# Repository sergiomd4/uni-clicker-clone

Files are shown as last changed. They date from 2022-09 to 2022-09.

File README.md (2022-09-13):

UNI Clicker Clone
========================================

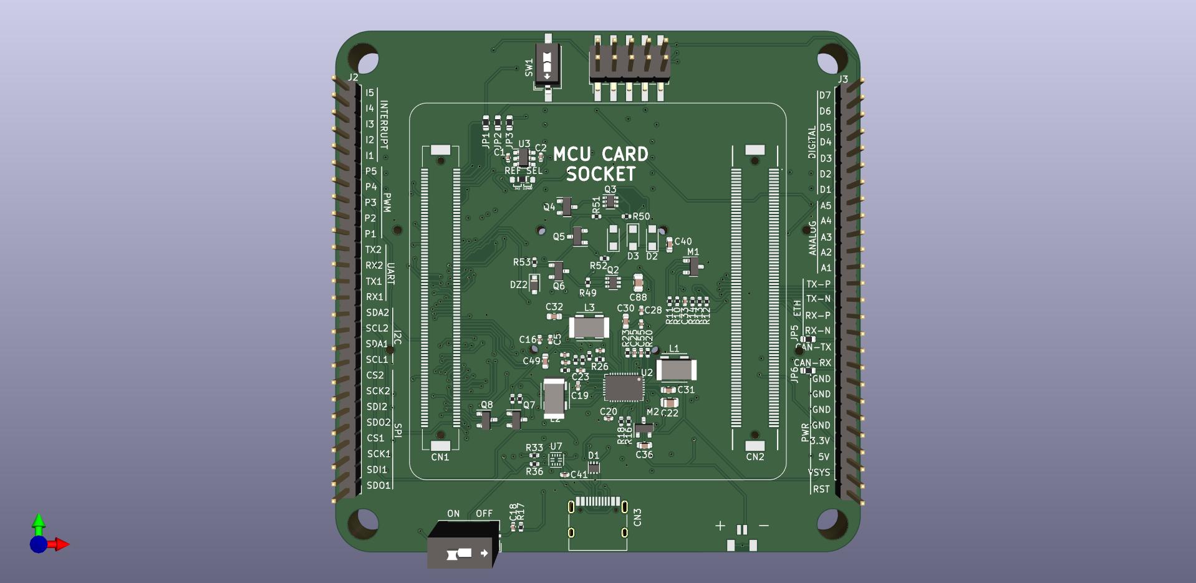
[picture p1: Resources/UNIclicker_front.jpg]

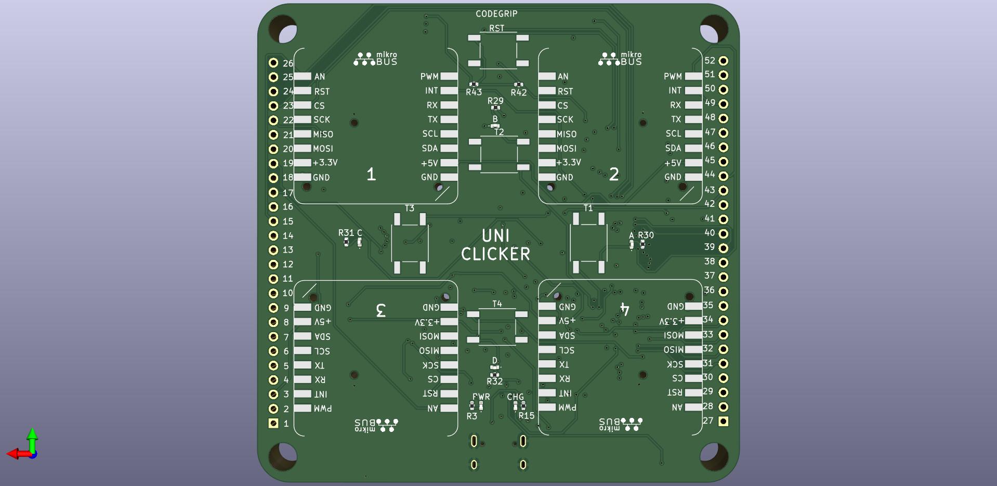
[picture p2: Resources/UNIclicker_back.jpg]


UNI Clicker is a compact development board designed as a complete solution. It contains a MCU Card socket, four mikroBUS sockets for Click boards connectivity and power management. 

Its core is a MCU Card socket that allows UNI Clicker to use different microcontrollers mounted on a standardized MCU Card. The MCU Card can be connected to the UNI Clicker by two 168-pin mezzanine connectors, one male and one female. This MCU Card supports architectures such as ARM, PIC32, dsPIC, PIC, AVR, Microchip, ST, NXP, TI and more.

UNI Clicker can be powered on by a small switch at the edge of the board. Therefore, the PSU (Power Supply Unit) module will be enabled and the power will be distributed. The PWR LED indicates that the board is ON.

Repository Contents
-------------------

* **/Production** - Gerber files, drill files, BOM, CPL file
* **/Hardware** - KiCad PCB files, footprints library
* **/Documents** - Schematics pdf

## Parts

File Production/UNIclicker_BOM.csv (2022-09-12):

Source: | C:\Users\Sergio\Documents\EOS\UNIclicker\UNIclicker\UNIclicker.kicad_sch
Date: | 29/08/2022 18:50:23
Tool: | Eeschema (6.0.7)
Generator: | C:\Program Files\KiCad\6.0\bin\scripting\plugins/bom_csv_grouped_by_value.py
Component Count: | 101
Individual Components:
Item | Qty | Reference(s) | Value | LibPart | Footprint | Datasheet | LCSC Part Number
 |  | C1 | 1u | Device:C | Capacitor_SMD:C_0402_1005Metric | ~ | C14445
 |  | C2 | 100n | Device:C | Capacitor_SMD:C_0402_1005Metric | ~ | C60474
 |  | C5 | 1u | Device:C | Capacitor_SMD:C_0402_1005Metric | ~ | C14445
 |  | C16 | 10000p | Device:C | Capacitor_SMD:C_0402_1005Metric | ~ | C60133
 |  | C18 | 0.1u | Device:C | Capacitor_SMD:C_0402_1005Metric | ~ | C1525
 |  | C19 | 2.2u | Device:C | Capacitor_SMD:C_0402_1005Metric | ~ | C107369
 |  | C20 | 2.2u | Device:C | Capacitor_SMD:C_0402_1005Metric | ~ | C107369
 |  | C21 | 33p | Device:C | Capacitor_SMD:C_0402_1005Metric | ~ | C1562
 |  | C22 | 47u | Device:C | Capacitor_SMD:C_0805_2012Metric | ~ | C16780
 |  | C23 | 10p | Device:C | Capacitor_SMD:C_0402_1005Metric | ~ | C696913
 |  | C24 | 300p | Device:C | Capacitor_SMD:C_0402_1005Metric | ~ | C1534
 |  | C25 | 0.1u | Device:C | Capacitor_SMD:C_0402_1005Metric | ~ | C1525
 |  | C27 | 1u | Device:C | Capacitor_SMD:C_0402_1005Metric | ~ | C14445
 |  | C28 | 10000p | Device:C | Capacitor_SMD:C_0402_1005Metric | ~ | C60133
 |  | C29 | 10p | Device:C | Capacitor_SMD:C_0402_1005Metric | ~ | C696913
 |  | C30 | 22u | Device:C | Capacitor_SMD:C_0603_1608Metric | ~ | C59461
 |  | C31 | 22u | Device:C | Capacitor_SMD:C_0603_1608Metric | ~ | C59461
 |  | C32 | 10u | Device:C | Capacitor_SMD:C_0603_1608Metric | ~ | C19702
 |  | C33 | 0.1u | Device:C | Capacitor_SMD:C_0402_1005Metric | ~ | C1525
 |  | C36 | 10u | Device:C | Capacitor_SMD:C_0603_1608Metric | ~ | C19702
 |  | C40 | 10u | Device:C | Capacitor_SMD:C_0603_1608Metric | ~ | C19702
 |  | C41 | 100n | Device:C | Capacitor_SMD:C_0402_1005Metric | ~ | C60474
 |  | C49 | 22u | Device:C | Capacitor_SMD:C_0603_1608Metric | ~ | C59461
 |  | C55 | 1u | Device:C | Capacitor_SMD:C_0402_1005Metric | ~ | C14445
 |  | C88 | 47u | Device:C | Capacitor_SMD:C_0805_2012Metric | ~ | C16780
 |  | CN1 | FX10A-168P-SV(71) | UNIclicker:MCU_CARD_SOCKET | EOS:FX10A-168P-SV(71) |  | C598050
 |  | CN2 | FX10A-168S-SV | UNIclicker:MCU_CARD_SOCKET | EOS:FX10A-168S-SV |  | C598051
 |  | CN3 | USB_C_Receptacle_USB2.0 | Connector:USB_C_Receptacle_USB2.0 | Connector_USB:USB_C_Receptacle_HRO_TYPE-C-31-M-12 | https://www.usb.org/sites/default/files/documents/usb_type-c.zip | C709357
 |  | D1 | USBLC6-2P6 | UNIclicker:USBLC6-2P6 | EOS:USBLC6-2P6 |  | C2827693
 |  | D2 | PMEG3010ER | Diode:PMEG3010ER | Diode_SMD:Nexperia_CFP3_SOD-123W | https://assets.nexperia.com/documents/data-sheet/PMEG3010ER.pdf | C456106
 |  | D3 | PMEG3010ER | Diode:PMEG3010ER | Diode_SMD:Nexperia_CFP3_SOD-123W | https://assets.nexperia.com/documents/data-sheet/PMEG3010ER.pdf | C456106
 |  | D4 | PMEG3010ER | Diode:PMEG3010ER | Diode_SMD:Nexperia_CFP3_SOD-123W | https://assets.nexperia.com/documents/data-sheet/PMEG3010ER.pdf | C456106
 |  | DZ2 | MM3Z3V3B | Device:D_Zener | EOS:MM3Z3V3B | ~ | C556407
 |  | J1 | DS1069-11 | UNIclicker:DS1069-11 | EOS:DS1069-11 |  | C160388
 |  | J10 | HM2X5 | Connector_Generic:Conn_02x05_Odd_Even | EOS:J10 | ~ | C124391
 |  | JP1 | 0.0 | Device:R | Resistor_SMD:R_0603_1608Metric | ~ | C122704
 |  | JP2 | 0.0 | Device:R | Resistor_SMD:R_0603_1608Metric | ~ | C122704
 |  | JP3 | 0.0 | Device:R | Resistor_SMD:R_0603_1608Metric | ~ | C122704
 |  | JP4 | REF SEL | Connector:Conn_01x03_Female | EOS:JP4 | ~ | C122704
 |  | JP5 | 0.0 | Device:R | Resistor_SMD:R_0603_1608Metric | ~ | C122704
 |  | JP6 | 0.0 | Device:R | Resistor_SMD:R_0603_1608Metric | ~ | C122704
 |  | L1 | 3.3u | Device:L | EOS:L1 | ~ | C15269
 |  | L2 | 2.2u | Device:L | EOS:L1 | ~ | C38117
 |  | L3 | 2.2u | Device:L | EOS:L1 | ~ | C38117
 |  | LED1 | CHG | Device:LED | LED_SMD:LED_0402_1005Metric | ~ | C965790
 |  | LED2 | PWR | Device:LED | LED_SMD:LED_0402_1005Metric | ~ | C434446
 |  | LED3 | A | Device:LED | LED_SMD:LED_0402_1005Metric | ~ | C965790
 |  | LED4 | B | Device:LED | LED_SMD:LED_0402_1005Metric | ~ | C965790
 |  | LED5 | C | Device:LED | LED_SMD:LED_0402_1005Metric | ~ | C965790
 |  | LED6 | D | Device:LED | LED_SMD:LED_0402_1005Metric | ~ | C965790
 |  | M1 | DMP2305U-7 | Transistor_FET:2N7002 | Package_TO_SOT_SMD:SOT-23 | https://www.onsemi.com/pub/Collateral/NDS7002A-D.PDF | C85097
 |  | M2 | DMP2305U-7 | Transistor_FET:2N7002 | Package_TO_SOT_SMD:SOT-23 | https://www.onsemi.com/pub/Collateral/NDS7002A-D.PDF | C85097
 |  | Q2 | DMP1046UFDB-7 | Transistor_FET:BSD235C | Package_TO_SOT_SMD:SOT-363_SC-70-6 | https://www.infineon.com/dgdl/Infineon-BSD235C-DS-v02_04-EN.pdf?fileId=db3a30433580b371013585a2d0d53326 | C131781
 |  | Q3 | DMP1046UFDB-7 | Transistor_FET:BSD235C | Package_TO_SOT_SMD:SOT-363_SC-70-6 | https://www.infineon.com/dgdl/Infineon-BSD235C-DS-v02_04-EN.pdf?fileId=db3a30433580b371013585a2d0d53326 | C131781
 |  | Q4 | BSS138 | Transistor_FET:BSS138 | Package_TO_SOT_SMD:SOT-23 | https://www.onsemi.com/pub/Collateral/BSS138-D.PDF | C112239
 |  | Q5 | BSS138 | Transistor_FET:BSS138 | Package_TO_SOT_SMD:SOT-23 | https://www.onsemi.com/pub/Collateral/BSS138-D.PDF | C112239
 |  | Q6 | BSS138 | Transistor_FET:BSS138 | Package_TO_SOT_SMD:SOT-23 | https://www.onsemi.com/pub/Collateral/BSS138-D.PDF | C112239
 |  | Q7 | DMG3420U-7 | Transistor_FET:2N7002 | Package_TO_SOT_SMD:SOT-23 | https://www.onsemi.com/pub/Collateral/NDS7002A-D.PDF | C154722
 |  | Q8 | DMG3420U-7 | Transistor_FET:2N7002 | Package_TO_SOT_SMD:SOT-23 | https://www.onsemi.com/pub/Collateral/NDS7002A-D.PDF | C154722
 |  | R3 | 470 | Device:R | Resistor_SMD:R_0402_1005Metric | ~ | C25117
 |  | R10 | 1M | Device:R | Resistor_SMD:R_0402_1005Metric | ~ | C93949
 |  | R11 | 1k | Device:R | Resistor_SMD:R_0402_1005Metric | ~ | C226166
 |  | R12 | 100k | Device:R | Resistor_SMD:R_0402_1005Metric | ~ | C25741
 |  | R13 | 100k | Device:R | Resistor_SMD:R_0402_1005Metric | ~ | C25741
 |  | R14 | 100k | Device:R | Resistor_SMD:R_0402_1005Metric | ~ | C25741
 |  | R15 | 2.2k | Device:R | Resistor_SMD:R_0402_1005Metric | ~ | C25879
 |  | R16 | 10k | Device:R | Resistor_SMD:R_0402_1005Metric | ~ | C140214
 |  | R17 | 1k | Device:R | Resistor_SMD:R_0402_1005Metric | ~ | C226166
 |  | R18 | 3.3k | Device:R | Resistor_SMD:R_0402_1005Metric | ~ | C25890
 |  | R19 | 324k | Device:R | Resistor_SMD:R_0402_1005Metric | ~ | C113480
 |  | R20 | 10k | Device:R | Resistor_SMD:R_0402_1005Metric | ~ | C140214
 |  | R21 | 15k | Device:R | Resistor_SMD:R_0402_1005Metric | ~ | C25756
 |  | R22 | 105k | Device:R | Resistor_SMD:R_0402_1005Metric | ~ | C25742
 |  | R23 | 1.69k | Device:R | Resistor_SMD:R_0402_1005Metric | ~ | C25870
 |  | R26 | 88.7k | Device:R | Resistor_SMD:R_0402_1005Metric | ~ | C25922
 |  | R27 | 16.9k | Device:R | Resistor_SMD:R_0402_1005Metric | ~ | C25858
 |  | R29 | 1k | Device:R | Resistor_SMD:R_0402_1005Metric | ~ | C226166
 |  | R30 | 1k | Device:R | Resistor_SMD:R_0402_1005Metric | ~ | C226166
 |  | R31 | 1k | Device:R | Resistor_SMD:R_0402_1005Metric | ~ | C226166
 |  | R32 | 1k | Device:R | Resistor_SMD:R_0402_1005Metric | ~ | C226166
 |  | R33 | 1k | Device:R | Resistor_SMD:R_0402_1005Metric | ~ | C226166
 |  | R36 | 4.7k | Device:R | Resistor_SMD:R_0402_1005Metric | ~ | C304616
 |  | R40 | 10k | Device:R | Resistor_SMD:R_0402_1005Metric | ~ | C140214
 |  | R41 | 100k | Device:R | Resistor_SMD:R_0402_1005Metric | ~ | C25741
 |  | R42 | 10k | Device:R | Resistor_SMD:R_0402_1005Metric | ~ | C140214
 |  | R43 | 330 | Device:R | Resistor_SMD:R_0402_1005Metric | ~ | C12246
 |  | R49 | 10k | Device:R | Resistor_SMD:R_0402_1005Metric | ~ | C140214
 |  | R50 | 47k | Device:R | Resistor_SMD:R_0402_1005Metric | ~ | C25563
 |  | R51 | 10k | Device:R | Resistor_SMD:R_0402_1005Metric | ~ | C140214
 |  | R52 | 5.1k | Device:R | Resistor_SMD:R_0402_1005Metric | ~ | C25905
 |  | R53 | 12.1k | Device:R | Resistor_SMD:R_0402_1005Metric | ~ | C25852
 |  | SW1 | CHS-01TB | Switch:SW_DIP_x01 | EOS:CHS-01TB | ~ | C54948
 |  | SW2 | JS202011JCQN | UNIclicker:JS202011JCQN | EOS:JS202011JCQN |  | C221665
 |  | T1 | SW_Push_Dual | Switch:SW_Push_Dual | EOS:PUSH_BUTTON | ~ | C127509
 |  | T2 | SW_Push_Dual | Switch:SW_Push_Dual | EOS:PUSH_BUTTON | ~ | C127509
 |  | T3 | SW_Push_Dual | Switch:SW_Push_Dual | EOS:PUSH_BUTTON | ~ | C127509
 |  | T4 | SW_Push_Dual | Switch:SW_Push_Dual | EOS:PUSH_BUTTON | ~ | C127509
 |  | T5 | SW_Push_Dual | Switch:SW_Push_Dual | EOS:PUSH_BUTTON | ~ | C127509
 |  | U2 | LTC3586EUFE | UNIclicker:LTC3586EUFE | Package_DFN_QFN:QFN-38-1EP_4x6mm_P0.4mm_EP2.65x4.65mm |  | C685109
 |  | U3 | MCP1501T-20E/RW | UNIclicker:MCP1501T-20E{slash}RW | Package_TO_SOT_SMD:SOT-23-6 |  | C98139
 |  | U7 | PTN5150AHXMP | UNIclicker:PTN5150AHXMP | EOS:PTN5150AHXMP |  | C2651889

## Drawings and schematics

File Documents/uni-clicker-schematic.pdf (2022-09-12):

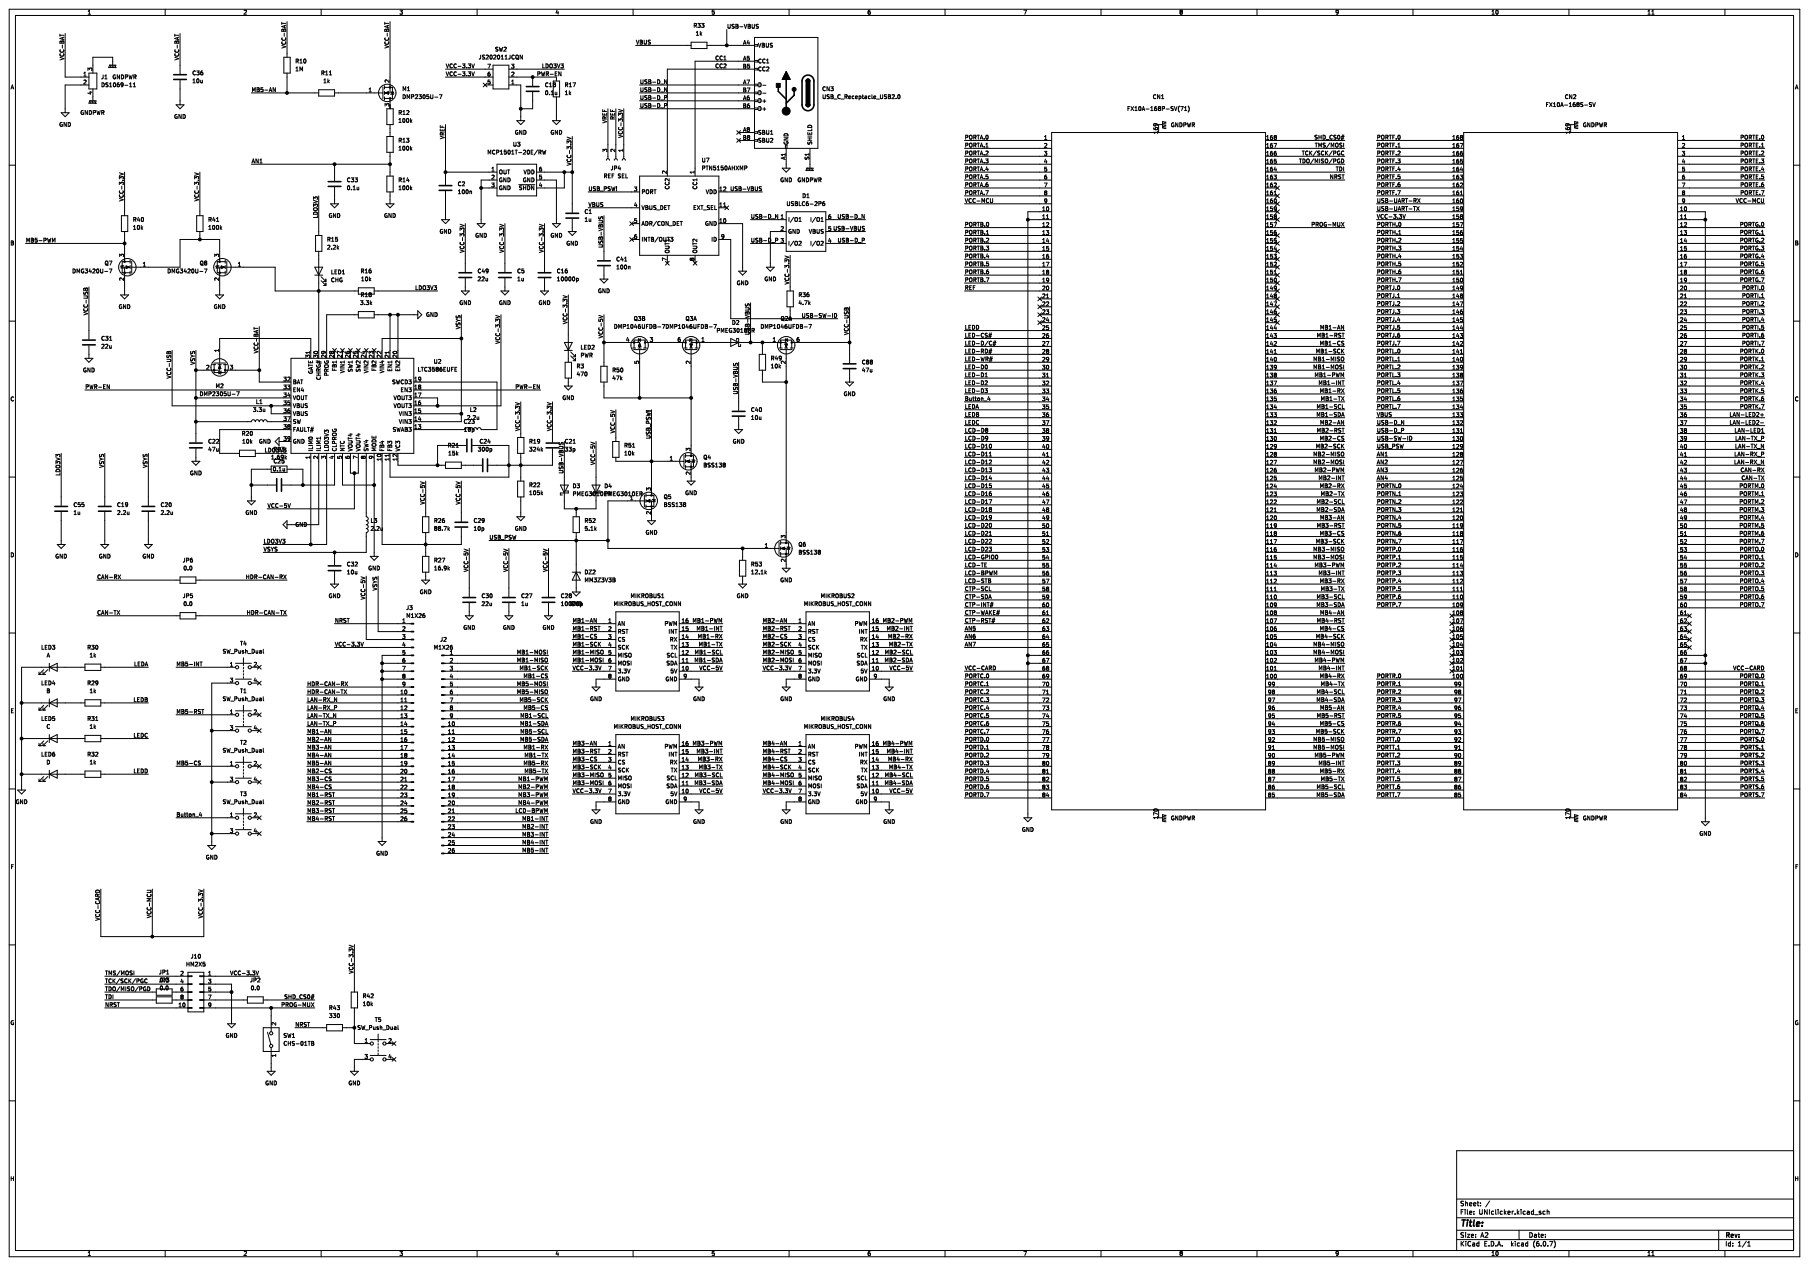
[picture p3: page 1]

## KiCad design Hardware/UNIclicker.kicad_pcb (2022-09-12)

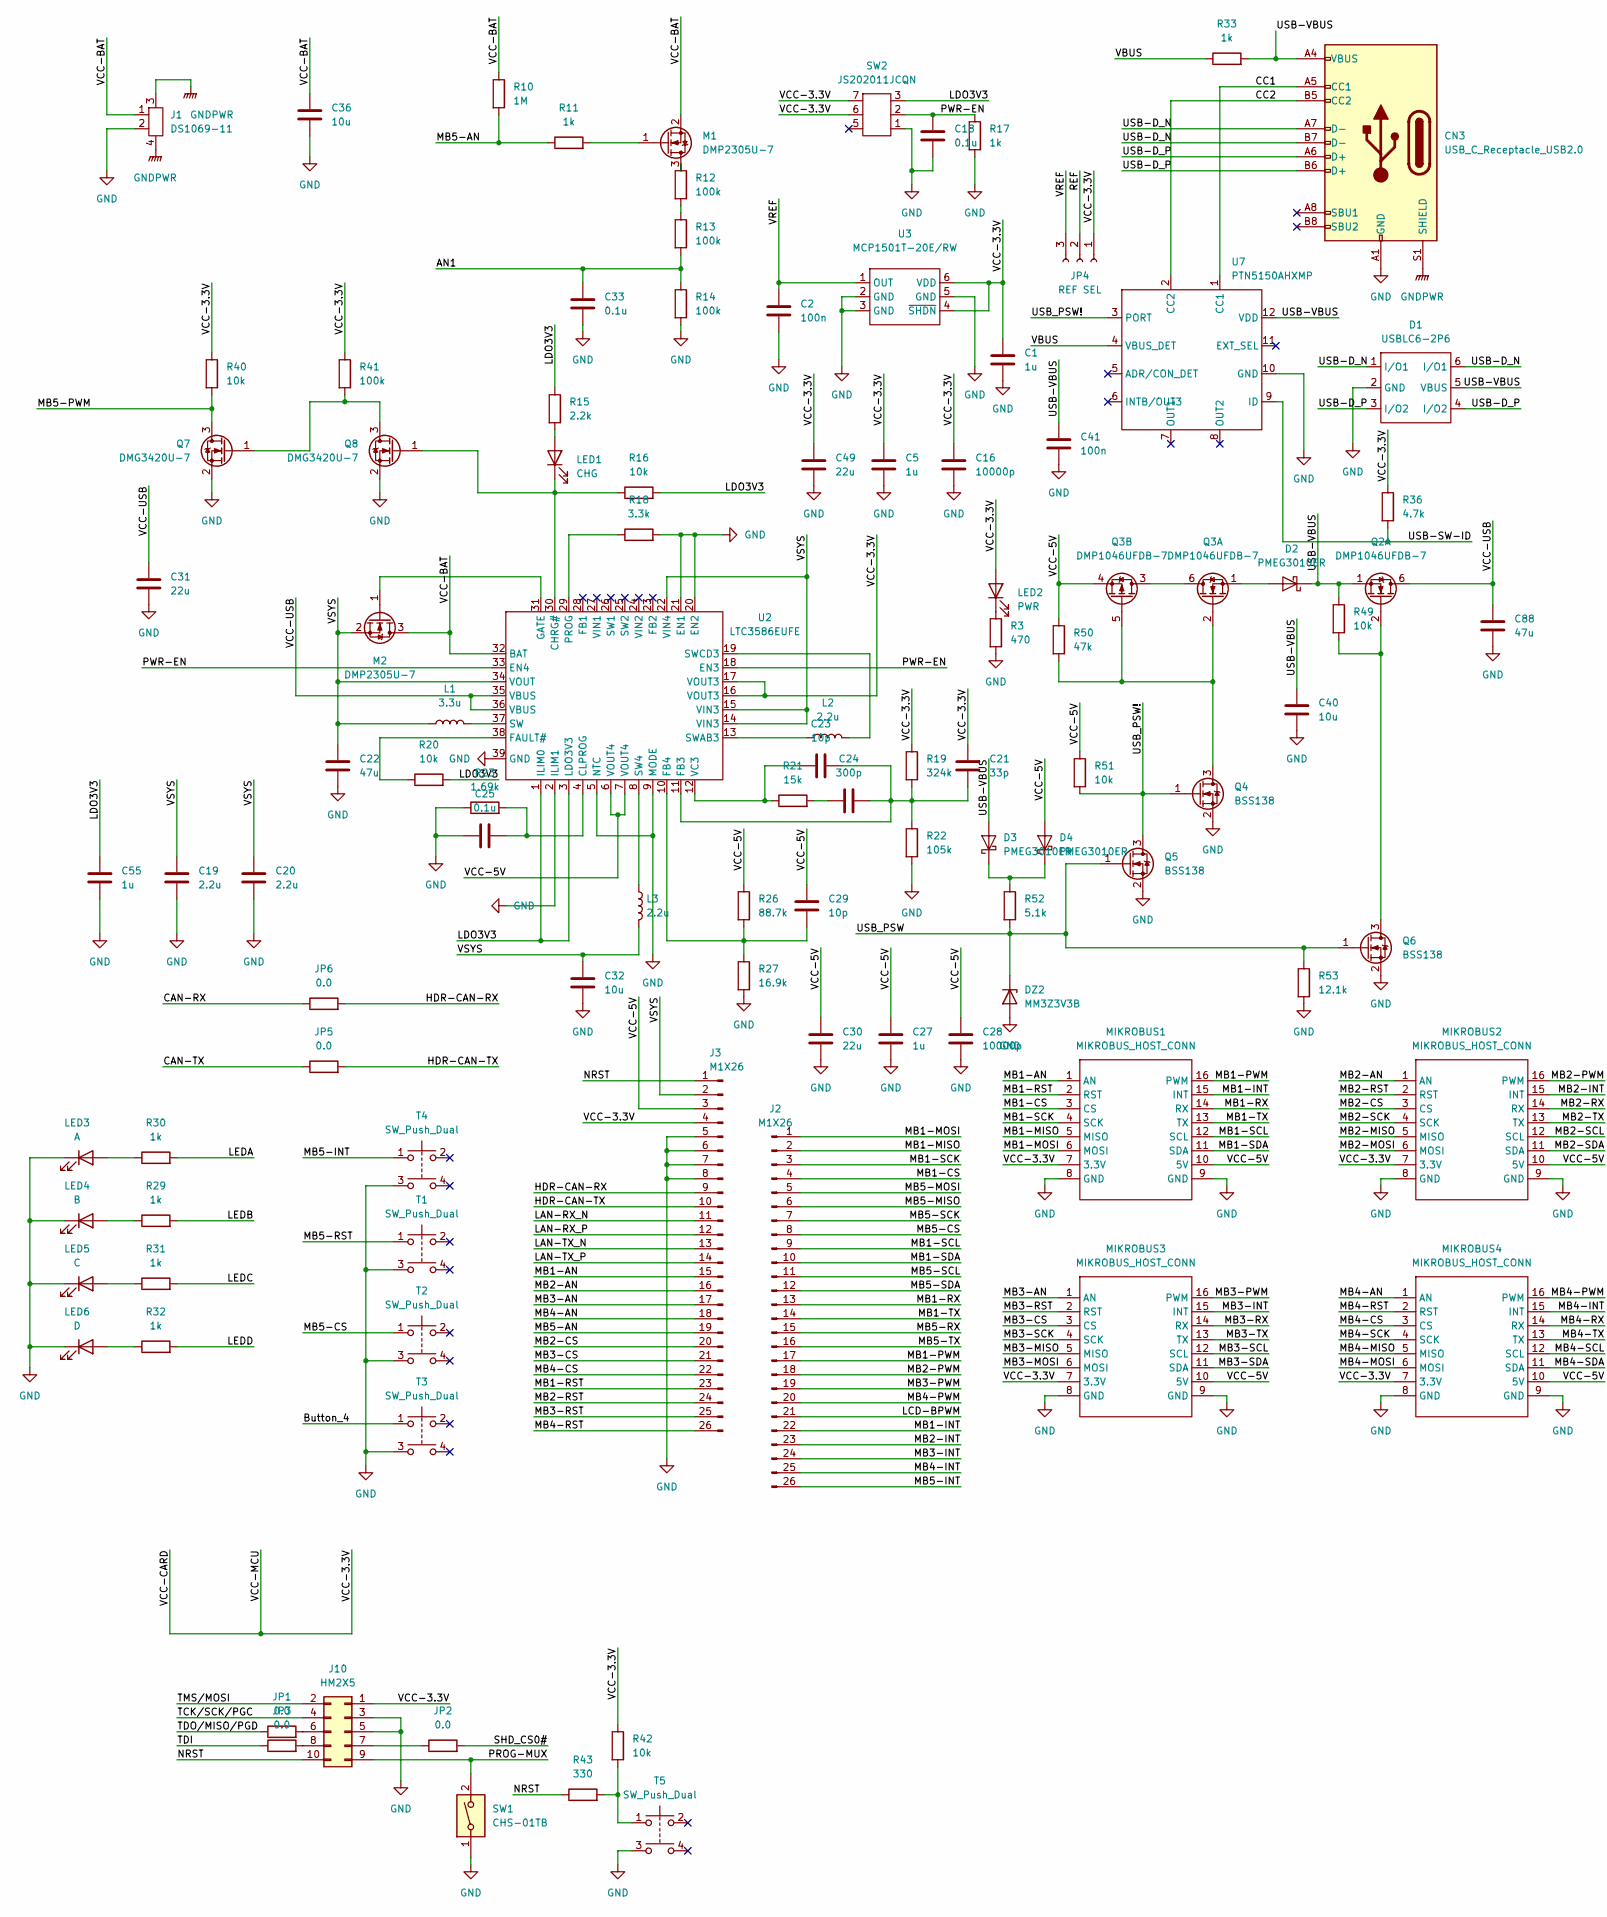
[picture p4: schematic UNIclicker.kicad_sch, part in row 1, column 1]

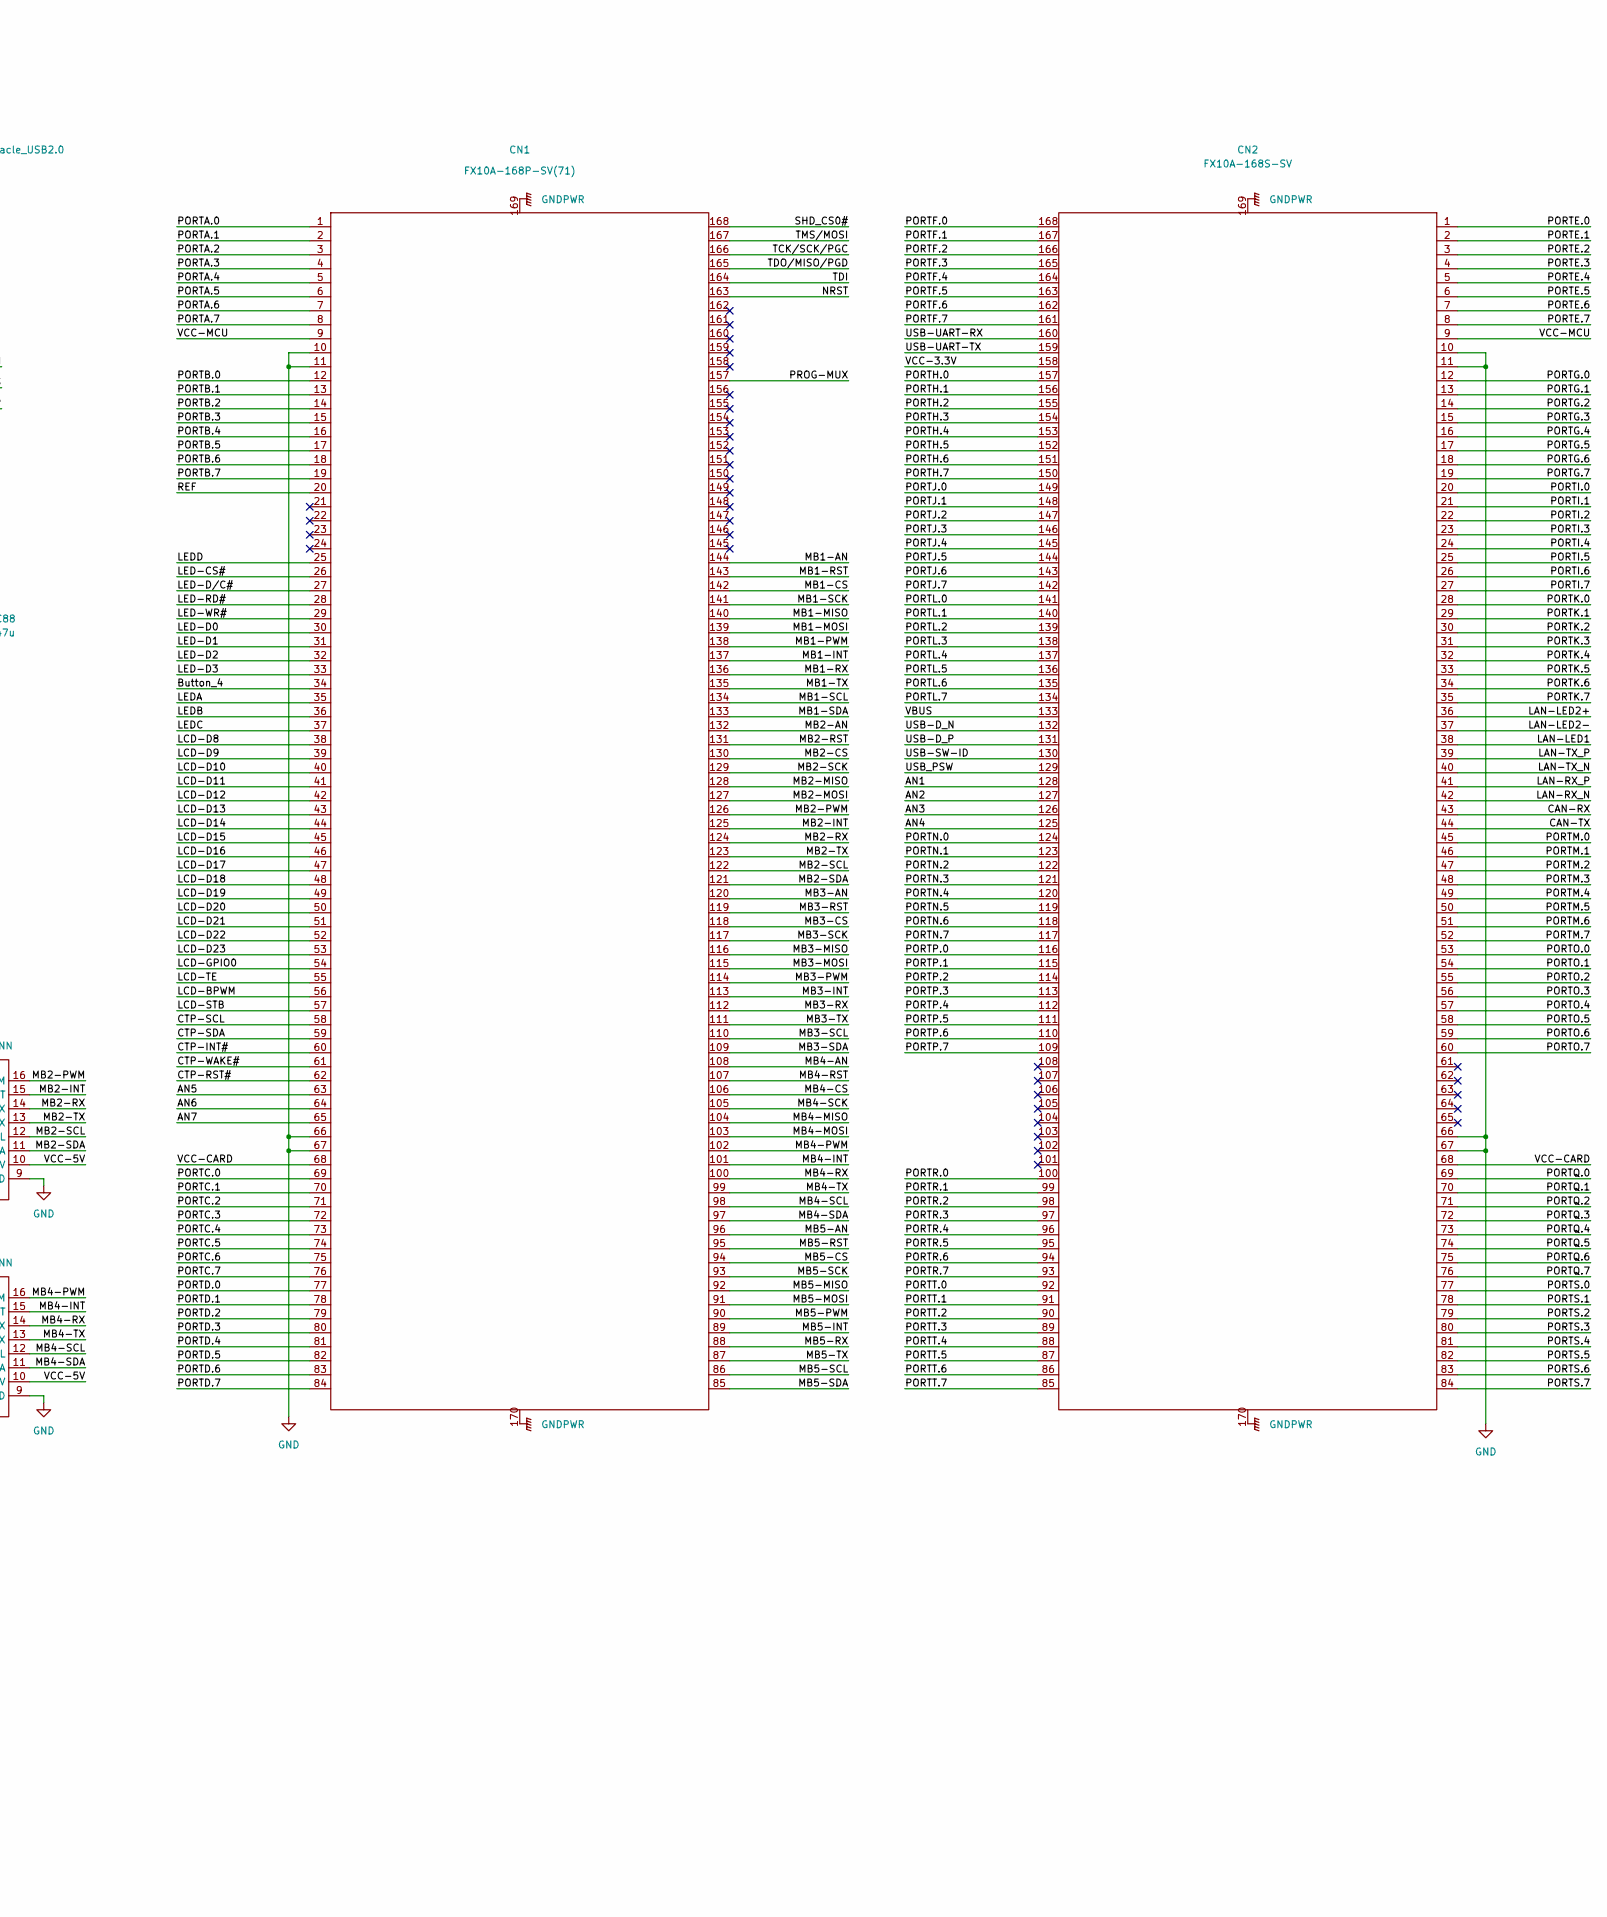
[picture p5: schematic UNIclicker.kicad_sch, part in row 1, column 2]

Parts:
C1, C5, C27, C55: 1u; C_0402_1005Metric; LCSC Part Number C14445
C2, C41: 100n; C_0402_1005Metric; LCSC Part Number C60474
C16, C28: 10000p; C_0402_1005Metric; LCSC Part Number C60133
C18, C25, C33: 0.1u; C_0402_1005Metric; LCSC Part Number C1525
C19, C20: 2.2u; C_0402_1005Metric; LCSC Part Number C107369
C21: 33p; C_0402_1005Metric; LCSC Part Number C1562
C22, C88: 47u; C_0805_2012Metric; LCSC Part Number C16780
C23, C29: 10p; C_0402_1005Metric; LCSC Part Number C696913
C24: 300p; C_0402_1005Metric; LCSC Part Number C1534
C30, C31, C49: 22u; C_0603_1608Metric; LCSC Part Number C59461
C32, C36, C40: 10u; C_0603_1608Metric; LCSC Part Number C19702
CN1: FX10A-168P-SV(71); LCSC Part Number C598050
CN2: FX10A-168S-SV; LCSC Part Number C598051
CN3: USB_C_Receptacle_USB2.0; USB_C_Receptacle_HRO_TYPE-C-31-M-12; LCSC Part Number C709357
D1: USBLC6-2P6; LCSC Part Number C2827693
D2, D3, D4: PMEG3010ER; Nexperia_CFP3_SOD-123W; LCSC Part Number C456106
DZ2: MM3Z3V3B; LCSC Part Number C556407
J1: DS1069-11; LCSC Part Number C160388
J2, J3: M1X26; PinHeader_1x26_P2.54mm_Vertical
J10: HM2X5; J10; LCSC Part Number C124391
JP1, JP2, JP3, JP5, JP6: 0.0; R_0603_1608Metric; LCSC Part Number C122704
JP4: REF SEL; JP4; LCSC Part Number C122704
L1: 3.3u; L1; LCSC Part Number C15269
L2, L3: 2.2u; L1; LCSC Part Number C38117
LED1: CHG; LED_0402_1005Metric; LCSC Part Number C965790
LED2: PWR; LED_0402_1005Metric; LCSC Part Number C434446
LED3: A; LED_0402_1005Metric; LCSC Part Number C965790
LED4: B; LED_0402_1005Metric; LCSC Part Number C965790
LED5: C; LED_0402_1005Metric; LCSC Part Number C965790
LED6: D; LED_0402_1005Metric; LCSC Part Number C965790
M1, M2: DMP2305U-7; SOT-23; LCSC Part Number C85097
MIKROBUS1, MIKROBUS2, MIKROBUS3, MIKROBUS4: MIKROBUS_HOST_CONN; SOCKET MIKROBUS
Q2, Q3: DMP1046UFDB-7; SOT-363_SC-70-6; LCSC Part Number C131781
Q4, Q5, Q6: BSS138; SOT-23; LCSC Part Number C112239
Q7, Q8: DMG3420U-7; SOT-23; LCSC Part Number C154722
R3: 470; R_0402_1005Metric; LCSC Part Number C25117
R10: 1M; R_0402_1005Metric; LCSC Part Number C93949
R11, R17, R29, R30, R31, R32, R33: 1k; R_0402_1005Metric; LCSC Part Number C226166
R12, R13, R14, R41: 100k; R_0402_1005Metric; LCSC Part Number C25741
R15: 2.2k; R_0402_1005Metric; LCSC Part Number C25879
R16, R20, R40, R42, R49, R51: 10k; R_0402_1005Metric; LCSC Part Number C140214
R18: 3.3k; R_0402_1005Metric; LCSC Part Number C25890
R19: 324k; R_0402_1005Metric; LCSC Part Number C113480
R21: 15k; R_0402_1005Metric; LCSC Part Number C25756
R22: 105k; R_0402_1005Metric; LCSC Part Number C25742
R23: 1.69k; R_0402_1005Metric; LCSC Part Number C25870
R26: 88.7k; R_0402_1005Metric; LCSC Part Number C25922
R27: 16.9k; R_0402_1005Metric; LCSC Part Number C25858
R36: 4.7k; R_0402_1005Metric; LCSC Part Number C304616
R43: 330; R_0402_1005Metric; LCSC Part Number C12246
R50: 47k; R_0402_1005Metric; LCSC Part Number C25563
R52: 5.1k; R_0402_1005Metric; LCSC Part Number C25905
R53: 12.1k; R_0402_1005Metric; LCSC Part Number C25852
SW1: CHS-01TB; LCSC Part Number C54948
SW2: JS202011JCQN; LCSC Part Number C221665
T1, T2, T3, T4, T5: SW_Push_Dual; PUSH_BUTTON; LCSC Part Number C127509
U2: LTC3586EUFE; QFN-38-1EP_4x6mm_P0.4mm_EP2.65x4.65mm
U3: MCP1501T-20E/RW; SOT-23-6
U7: PTN5150AHXMP

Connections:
/AN1: C33.1, CN2.128, R13.2, R14.1
/AN2: CN2.127
/AN3: CN2.126
/AN4: CN2.125
/AN5: CN1.63
/AN6: CN1.64
/AN7: CN1.65
/Button_4: CN1.34, T3.1
/CAN-RX: CN2.43, JP6.1
/CAN-TX: CN2.44, JP5.1
/CC1: CN3.A5 (CC1), U7.1 (CC1)
/CC2: CN3.B5 (CC2), U7.2 (CC2)
/CTP-INT#: CN1.60
/CTP-RST#: CN1.62
/CTP-SCL: CN1.58
/CTP-SDA: CN1.59
/CTP-WAKE#: CN1.61
/HDR-CAN-RX: J3.9, JP6.2
/HDR-CAN-TX: J3.10, JP5.2
/LAN-LED1: CN2.38
/LAN-LED2+: CN2.36
/LAN-LED2-: CN2.37
/LAN-RX_N: CN2.42, J3.11
/LAN-RX_P: CN2.41, J3.12
/LAN-TX_N: CN2.40, J3.13
/LAN-TX_P: CN2.39, J3.14
/LCD-BPWM: CN1.56, J2.21
/LCD-D8: CN1.38
/LCD-D9: CN1.39
/LCD-D10: CN1.40
/LCD-D11: CN1.41
/LCD-D12: CN1.42
/LCD-D13: CN1.43
/LCD-D14: CN1.44
/LCD-D15: CN1.45
/LCD-D16: CN1.46
/LCD-D17: CN1.47
/LCD-D18: CN1.48
/LCD-D19: CN1.49
/LCD-D20: CN1.50
/LCD-D21: CN1.51
/LCD-D22: CN1.52
/LCD-D23: CN1.53
/LCD-GPIO0: CN1.54
/LCD-STB: CN1.57
/LCD-TE: CN1.55
/LDO3V3: C55.1, R15.1, R16.2, R20.2, SW2.3, U2.1 (ILIM0), U2.3 (LDO3V3)
/LED-CS#: CN1.26
/LED-D0: CN1.30
/LED-D1: CN1.31
/LED-D2: CN1.32
/LED-D3: CN1.33
/LED-D/C#: CN1.27
/LED-RD#: CN1.28
/LED-WR#: CN1.29
/LEDA: CN1.35, R30.2
/LEDB: CN1.36, R29.2
/LEDC: CN1.37, R31.2
/LEDD: CN1.25, R32.2
/MB1-AN: CN1.144, J3.15, MIKROBUS1.1 (AN)
/MB1-CS: CN1.142, J2.4, MIKROBUS1.3 (CS)
/MB1-INT: CN1.137, J2.22, MIKROBUS1.15 (INT)
/MB1-MISO: CN1.140, J2.2, MIKROBUS1.5 (MISO)
/MB1-MOSI: CN1.139, J2.1, MIKROBUS1.6 (MOSI)
/MB1-PWM: CN1.138, J2.17, MIKROBUS1.16 (PWM)
/MB1-RST: CN1.143, J3.23, MIKROBUS1.2 (RST)
/MB1-RX: CN1.136, J2.13, MIKROBUS1.14 (RX)
/MB1-SCK: CN1.141, J2.3, MIKROBUS1.4 (SCK)
/MB1-SCL: CN1.134, J2.9, MIKROBUS1.12 (SCL)
/MB1-SDA: CN1.133, J2.10, MIKROBUS1.11 (SDA)
/MB1-TX: CN1.135, J2.14, MIKROBUS1.13 (TX)
/MB2-AN: CN1.132, J3.16, MIKROBUS2.1 (AN)
/MB2-CS: CN1.130, J3.20, MIKROBUS2.3 (CS)
/MB2-INT: CN1.125, J2.23, MIKROBUS2.15 (INT)
/MB2-MISO: CN1.128, MIKROBUS2.5 (MISO)
/MB2-MOSI: CN1.127, MIKROBUS2.6 (MOSI)
/MB2-PWM: CN1.126, J2.18, MIKROBUS2.16 (PWM)
/MB2-RST: CN1.131, J3.24, MIKROBUS2.2 (RST)
/MB2-RX: CN1.124, MIKROBUS2.14 (RX)
/MB2-SCK: CN1.129, MIKROBUS2.4 (SCK)
/MB2-SCL: CN1.122, MIKROBUS2.12 (SCL)
/MB2-SDA: CN1.121, MIKROBUS2.11 (SDA)
/MB2-TX: CN1.123, MIKROBUS2.13 (TX)
/MB3-AN: CN1.120, J3.17, MIKROBUS3.1 (AN)
/MB3-CS: CN1.118, J3.21, MIKROBUS3.3 (CS)
/MB3-INT: CN1.113, J2.24, MIKROBUS3.15 (INT)
/MB3-MISO: CN1.116, MIKROBUS3.5 (MISO)
/MB3-MOSI: CN1.115, MIKROBUS3.6 (MOSI)
/MB3-PWM: CN1.114, J2.19, MIKROBUS3.16 (PWM)
/MB3-RST: CN1.119, J3.25, MIKROBUS3.2 (RST)
/MB3-RX: CN1.112, MIKROBUS3.14 (RX)
/MB3-SCK: CN1.117, MIKROBUS3.4 (SCK)
/MB3-SCL: CN1.110, MIKROBUS3.12 (SCL)
/MB3-SDA: CN1.109, MIKROBUS3.11 (SDA)
/MB3-TX: CN1.111, MIKROBUS3.13 (TX)
/MB4-AN: CN1.108, J3.18, MIKROBUS4.1 (AN)
/MB4-CS: CN1.106, J3.22, MIKROBUS4.3 (CS)
/MB4-INT: CN1.101, J2.25, MIKROBUS4.15 (INT)
/MB4-MISO: CN1.104, MIKROBUS4.5 (MISO)
/MB4-MOSI: CN1.103, MIKROBUS4.6 (MOSI)
/MB4-PWM: CN1.102, J2.20, MIKROBUS4.16 (PWM)
/MB4-RST: CN1.107, J3.26, MIKROBUS4.2 (RST)
/MB4-RX: CN1.100, MIKROBUS4.14 (RX)
/MB4-SCK: CN1.105, MIKROBUS4.4 (SCK)
/MB4-SCL: CN1.98, MIKROBUS4.12 (SCL)
/MB4-SDA: CN1.97, MIKROBUS4.11 (SDA)
/MB4-TX: CN1.99, MIKROBUS4.13 (TX)
/MB5-AN: CN1.96, J3.19, R10.2, R11.1
/MB5-CS: CN1.94, J2.8, T2.1
/MB5-INT: CN1.89, J2.26, T4.1
/MB5-MISO: CN1.92, J2.6
/MB5-MOSI: CN1.91, J2.5
/MB5-PWM: CN1.90, Q7.3 (D), R40.2
/MB5-RST: CN1.95, T1.1
/MB5-RX: CN1.88, J2.15
/MB5-SCK: CN1.93, J2.7
/MB5-SCL: CN1.86, J2.11
/MB5-SDA: CN1.85, J2.12
/MB5-TX: CN1.87, J2.16
/NRST: CN1.163, J3.1, J10.10, R43.1
/PORTA.0: CN1.1
/PORTA.1: CN1.2
/PORTA.2: CN1.3
/PORTA.3: CN1.4
/PORTA.4: CN1.5
/PORTA.5: CN1.6
/PORTA.6: CN1.7
/PORTA.7: CN1.8
/PORTB.0: CN1.12
/PORTB.1: CN1.13
/PORTB.2: CN1.14
/PORTB.3: CN1.15
/PORTB.4: CN1.16
/PORTB.5: CN1.17
/PORTB.6: CN1.18
/PORTB.7: CN1.19
/PORTC.0: CN1.69
/PORTC.1: CN1.70
/PORTC.2: CN1.71
/PORTC.3: CN1.72
/PORTC.4: CN1.73
/PORTC.5: CN1.74
/PORTC.6: CN1.75
/PORTC.7: CN1.76
/PORTD.0: CN1.77
/PORTD.1: CN1.78
/PORTD.2: CN1.79
/PORTD.3: CN1.80
/PORTD.4: CN1.81
/PORTD.5: CN1.82
/PORTD.6: CN1.83
/PORTD.7: CN1.84
/PORTE.0: CN2.1
/PORTE.1: CN2.2
/PORTE.2: CN2.3
/PORTE.3: CN2.4
/PORTE.4: CN2.5
/PORTE.5: CN2.6
/PORTE.6: CN2.7
/PORTE.7: CN2.8
/PORTF.0: CN2.168
/PORTF.1: CN2.167
/PORTF.2: CN2.166
/PORTF.3: CN2.165
/PORTF.4: CN2.164
/PORTF.5: CN2.163
/PORTF.6: CN2.162
/PORTF.7: CN2.161
/PORTG.0: CN2.12
/PORTG.1: CN2.13
/PORTG.2: CN2.14
/PORTG.3: CN2.15
/PORTG.4: CN2.16
/PORTG.5: CN2.17
/PORTG.6: CN2.18
/PORTG.7: CN2.19
/PORTH.0: CN2.157
/PORTH.1: CN2.156
/PORTH.2: CN2.155
/PORTH.3: CN2.154
/PORTH.4: CN2.153
/PORTH.5: CN2.152
/PORTH.6: CN2.151
/PORTH.7: CN2.150
/PORTI.0: CN2.20
/PORTI.1: CN2.21
/PORTI.2: CN2.22
/PORTI.3: CN2.23
/PORTI.4: CN2.24
/PORTI.5: CN2.25
/PORTI.6: CN2.26
/PORTI.7: CN2.27
/PORTJ.0: CN2.149
/PORTJ.1: CN2.148
/PORTJ.2: CN2.147
/PORTJ.3: CN2.146
/PORTJ.4: CN2.145
/PORTJ.5: CN2.144
/PORTJ.6: CN2.143
/PORTJ.7: CN2.142
/PORTK.0: CN2.28
/PORTK.1: CN2.29
/PORTK.2: CN2.30
/PORTK.3: CN2.31
/PORTK.4: CN2.32
/PORTK.5: CN2.33
/PORTK.6: CN2.34
/PORTK.7: CN2.35
/PORTL.0: CN2.141
/PORTL.1: CN2.140
/PORTL.2: CN2.139
/PORTL.3: CN2.138
/PORTL.4: CN2.137
/PORTL.5: CN2.136
/PORTL.6: CN2.135
/PORTL.7: CN2.134
/PORTM.0: CN2.45
/PORTM.1: CN2.46
/PORTM.2: CN2.47
/PORTM.3: CN2.48
/PORTM.4: CN2.49
/PORTM.5: CN2.50
/PORTM.6: CN2.51
/PORTM.7: CN2.52
/PORTN.0: CN2.124
/PORTN.1: CN2.123
/PORTN.2: CN2.122
/PORTN.3: CN2.121
/PORTN.4: CN2.120
/PORTN.5: CN2.119
/PORTN.6: CN2.118
/PORTN.7: CN2.117
/PORTO.0: CN2.53
/PORTO.1: CN2.54
/PORTO.2: CN2.55
/PORTO.3: CN2.56
/PORTO.4: CN2.57
/PORTO.5: CN2.58
/PORTO.6: CN2.59
/PORTO.7: CN2.60
/PORTP.0: CN2.116
/PORTP.1: CN2.115
/PORTP.2: CN2.114
/PORTP.3: CN2.113
/PORTP.4: CN2.112
/PORTP.5: CN2.111
/PORTP.6: CN2.110
/PORTP.7: CN2.109
/PORTQ.0: CN2.69
/PORTQ.1: CN2.70
/PORTQ.2: CN2.71
/PORTQ.3: CN2.72
/PORTQ.4: CN2.73
/PORTQ.5: CN2.74
/PORTQ.6: CN2.75
/PORTQ.7: CN2.76
/PORTR.0: CN2.100
/PORTR.1: CN2.99
/PORTR.2: CN2.98
/PORTR.3: CN2.97
/PORTR.4: CN2.96
/PORTR.5: CN2.95
/PORTR.6: CN2.94
/PORTR.7: CN2.93
/PORTS.0: CN2.77
/PORTS.1: CN2.78
/PORTS.2: CN2.79
/PORTS.3: CN2.80
/PORTS.4: CN2.81
/PORTS.5: CN2.82
/PORTS.6: CN2.83
/PORTS.7: CN2.84
/PORTT.0: CN2.92
/PORTT.1: CN2.91
/PORTT.2: CN2.90
/PORTT.3: CN2.89
/PORTT.4: CN2.88
/PORTT.5: CN2.87
/PORTT.6: CN2.86
/PORTT.7: CN2.85
/PROG-MUX: CN1.157, J10.9, SW1.2
/PWR-EN: C18.1, R17.1, SW2.2, U2.18 (EN3), U2.33 (EN4)
/REF: CN1.20, JP4.2
/SHD_CS0#: CN1.168, JP2.2
/TCK/SCK/PGC: CN1.166, J10.4
/TDI: CN1.164, JP3.1
/TDO/MISO/PGD: CN1.165, JP1.1
/TMS/MOSI: CN1.167, J10.2
/USB-D_N: CN2.132, CN3.A7 (D-), CN3.B7 (D-), D1.1 (I/O1), D1.6 (I/O1)
/USB-D_P: CN2.131, CN3.A6 (D+), CN3.B6 (D+), D1.3 (I/O2), D1.4 (I/O2)
/USB-SW-ID: CN2.130, R36.2, U7.9 (ID)
/USB-UART-RX: CN2.160
/USB-UART-TX: CN2.159
/USB-VBUS: C40.1, C41.1, CN3.A4 (VBUS), CN3.A9 (VBUS), CN3.B4 (VBUS), CN3.B9 (VBUS), D1.5 (VBUS), D2.1 (K), D3.2 (A), Q2.1 (SN), R33.2, R49.1, U7.12 (VDD)
/USB_PSW: CN2.129, DZ2.1 (K), Q5.1 (G), Q6.1 (G), R52.2, R53.1
/USB_PSW!: Q4.1 (G), Q5.3 (D), R51.2, U7.3 (PORT)
/VBUS: CN2.133, R33.1, U7.4 (VBUS_DET)
/VCC-3.3V: C1.1, C5.1, C16.1, C21.1, C49.1, CN1.9, CN1.68, CN2.9, CN2.68, CN2.158, J3.4, J10.1, JP4.1, LED2.2 (A), MIKROBUS1.7 (3.3V), MIKROBUS2.7 (3.3V), MIKROBUS3.7 (3.3V), MIKROBUS4.7 (3.3V), R19.1, R36.1, R40.1, R41.1, R42.1, SW2.6, SW2.7, U2.16 (VOUT3), U2.17 (VOUT3), U3.4 (~SHDN), U3.6 (VDD)
/VCC-5V: C27.1, C28.1, C29.1, C30.1, D4.2 (A), J3.3, MIKROBUS1.10 (5V), MIKROBUS2.10 (5V), MIKROBUS3.10 (5V), MIKROBUS4.10 (5V), Q3.4 (SP), R26.1, R50.1, R51.1, U2.6 (VOUT4), U2.7 (VOUT4)
/VCC-BAT: C36.1, J1.1, M1.2 (S), M2.3 (D), R10.1, U2.32 (BAT)
/VCC-USB: C31.1, C88.1, Q2.6 (DN), U2.35 (VBUS), U2.36 (VBUS)
/VREF: C2.1, JP4.3, U3.1 (OUT)
/VSYS: C19.1, C20.1, C22.1, C32.1, J3.2, L1.1, L3.2, M2.2 (S), U2.14 (VIN3), U2.15 (VIN3), U2.22 (VIN4), U2.34 (VOUT)
GND: C1.2, C2.2, C5.2, C16.2, C18.2, C19.2, C20.2, C22.2, C25.1, C27.2, C28.2, C30.2, C31.2, C32.2, C33.2, C36.2, C40.2, C41.2, C49.2, C55.2, C88.2, CN1.10, CN1.11, CN1.66, CN1.67, CN2.10, CN2.11, CN2.66, CN2.67, CN3.A1 (GND), CN3.A12 (GND), CN3.B1 (GND), CN3.B12 (GND), D1.2 (GND), DZ2.2 (A), J1.2, J3.5, J3.6, J3.7, J3.8, J10.3, J10.5, LED3.1 (K), LED4.1 (K), LED5.1 (K), LED6.1 (K), MIKROBUS1.8 (GND), MIKROBUS1.9 (GND), MIKROBUS2.8 (GND), MIKROBUS2.9 (GND), MIKROBUS3.8 (GND), MIKROBUS3.9 (GND), MIKROBUS4.8 (GND), MIKROBUS4.9 (GND), Q4.2 (S), Q5.2 (S), Q6.2 (S), Q7.2 (S), Q8.2 (S), R3.2, R14.2, R17.2, R18.2, R22.2, R23.1, R27.2, R53.2, SW1.1, SW2.1, T1.3, T2.3, T3.3, T4.3, T5.3, U2.2 (ILIM1), U2.5 (NTC), U2.9 (MODE), U2.20 (EN2), U2.21 (EN1), U2.39 (GND), U3.2 (GND), U3.3 (GND), U3.5 (GND), U7.10 (GND)
GNDPWR: CN1.169, CN1.170, CN2.169, CN2.170, CN3.S1 (SHIELD), J1.3, J1.4
unnamed: C21.2, C23.2, C24.2, R19.2, R22.1, U2.11 (FB3)
unnamed: C23.1, R21.1, U2.12 (VC3)
unnamed: C24.1, R21.2
unnamed: C25.2, R23.2, U2.4 (CLPROG)
unnamed: C29.2, R26.2, R27.1, U2.10 (FB4)
unnamed: D2.2 (A), Q3.1 (SN)
unnamed: D3.1 (K), D4.1 (K), R52.1
unnamed: J10.6, JP1.2
unnamed: J10.7, JP2.1
unnamed: J10.8, JP3.2
unnamed: L1.2, U2.37 (SW)
unnamed: L2.1, U2.13 (SWAB3)
unnamed: L2.2, U2.19 (SWCD3)
unnamed: L3.1, U2.8 (SW4)
unnamed: LED1.1 (K), Q8.1 (G), R16.1, U2.30 (CHRG#)
unnamed: LED1.2 (A), R15.2
unnamed: LED2.1 (K), R3.1
unnamed: LED3.2 (A), R30.1
unnamed: LED4.2 (A), R29.1
unnamed: LED5.2 (A), R31.1
unnamed: LED6.2 (A), R32.1
unnamed: M1.1 (G), R11.2
unnamed: M1.3 (D), R12.1
unnamed: M2.1 (G), U2.31 (GATE)
unnamed: Q2.2 (GN), Q6.3 (D), R49.2
unnamed: Q3.2 (GN), Q3.5 (GP), Q4.3 (D), R50.2
unnamed: Q3.3 (DP), Q3.6 (DN)
unnamed: Q7.1 (G), Q8.3 (D), R41.2
unnamed: R12.2, R13.1
unnamed: R18.1, U2.29 (PROG)
unnamed: R20.1, U2.38 (FAULT#)
unnamed: R42.2, R43.2, T5.1

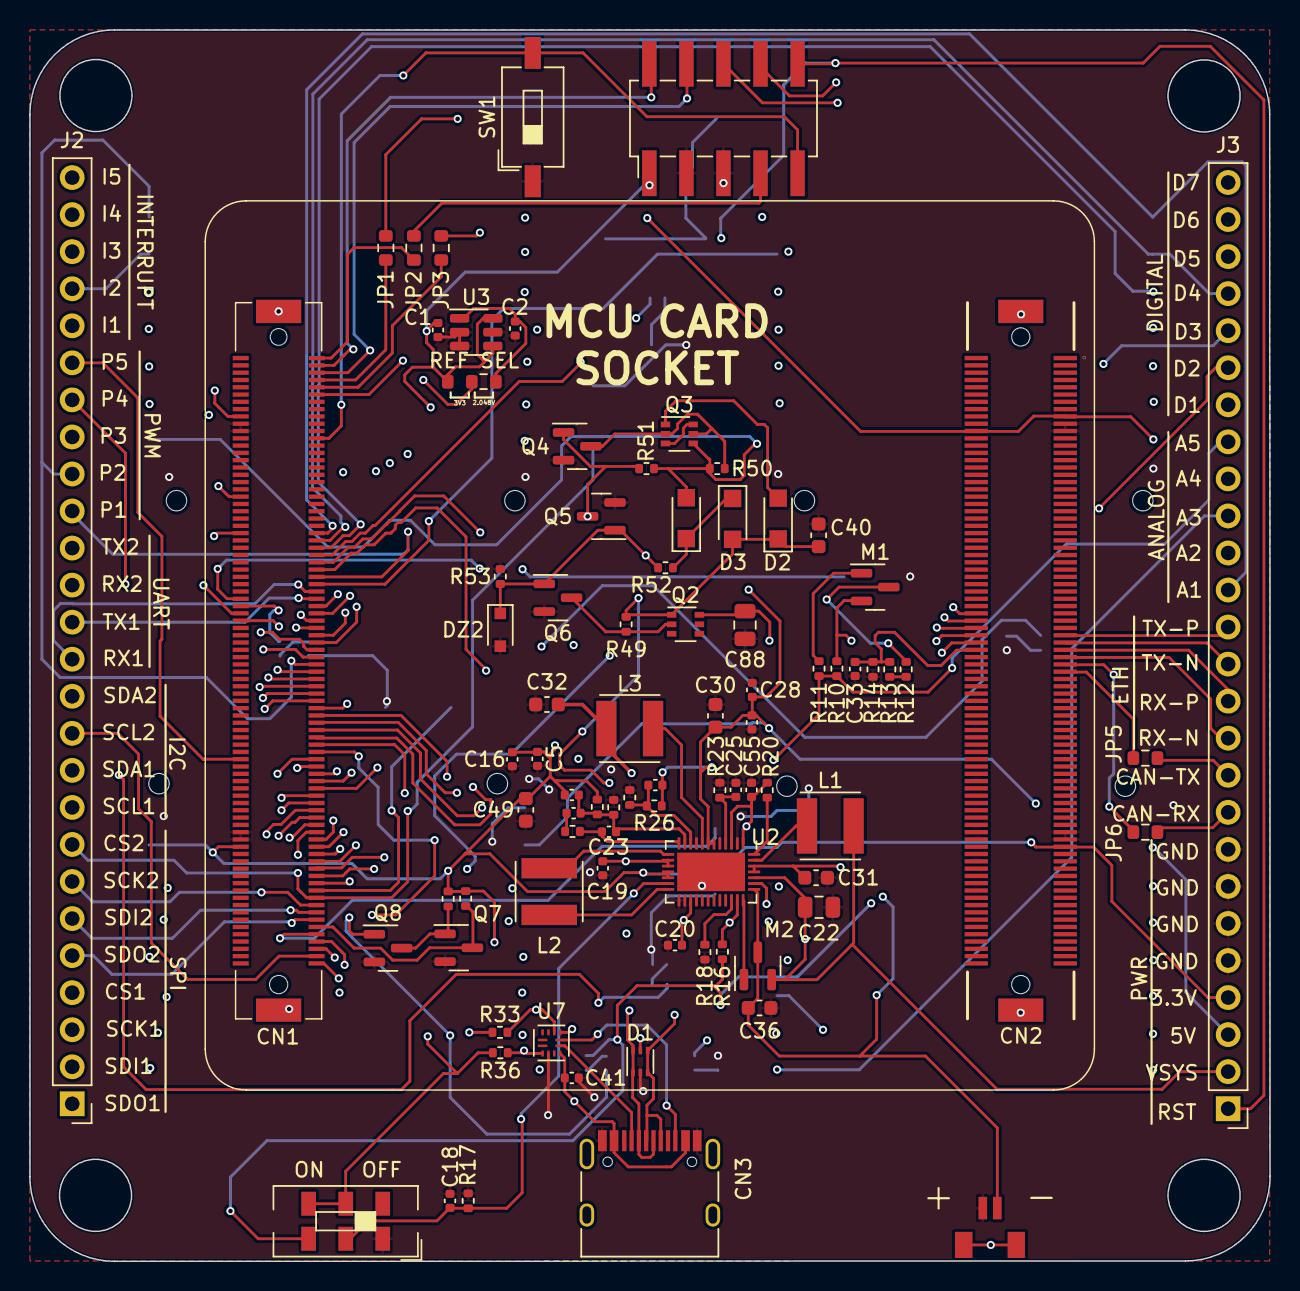
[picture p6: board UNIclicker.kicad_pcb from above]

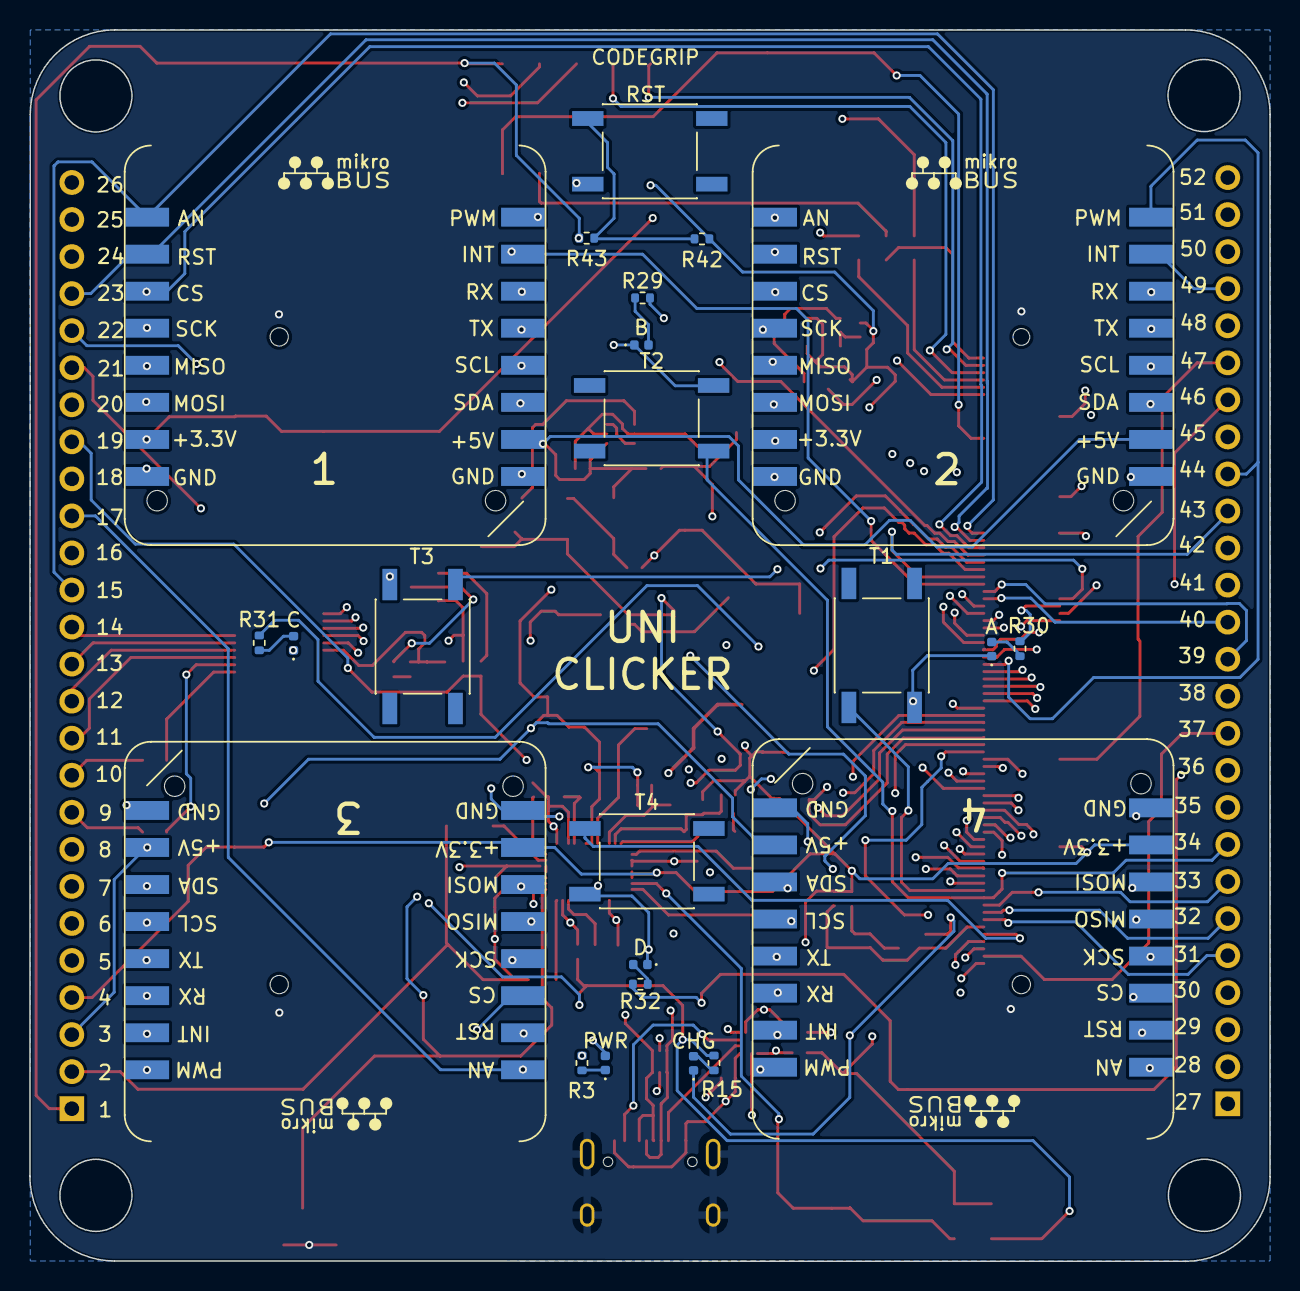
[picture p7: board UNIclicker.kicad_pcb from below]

Board: 4 copper layers, 85.0 x 84.4 mm, 107 parts (23 on the bottom side), 134 nets.

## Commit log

2022-09-12 Add schematic
2022-09-12 Add Gerber Files
    [UNIclicker-B_Cu.gbr, UNIclicker-B_Mask.gbr, UNIclicker-B_Paste.gbr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]
2022-09-12 Add Drill Files
    [UNIclicker-NPTH.drl, UNIclicker-PTH.drl]
2022-09-12 Add BOM
    [UNIclicker_BOM.csv]
2022-09-12 Add CPL file
    [UNIclicker-all-pos.csv]
2022-09-12 Add KiCad files
    [UNIclicker.kicad_pcb, UNIclicker.kicad_sch]
